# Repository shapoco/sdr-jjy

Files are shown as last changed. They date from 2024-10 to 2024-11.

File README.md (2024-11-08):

# SDR JJY (WIP)

試行錯誤中。

## ハードウェア

恥ずかしながらネットで見つけた構成の切り貼りとカットアンドトライの結果であるため、多分あちこちおかしいと思います。

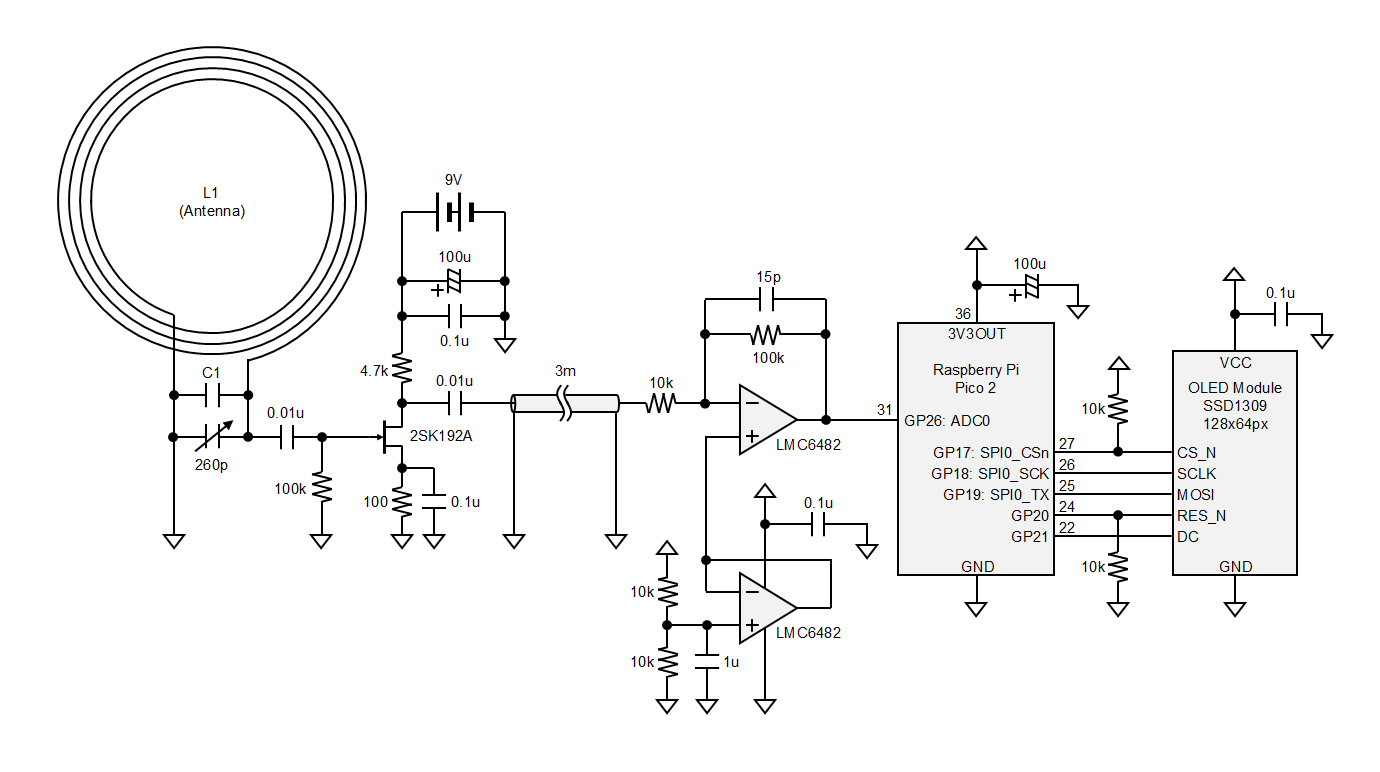
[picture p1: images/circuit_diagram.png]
回路図


市販の電波時計でも窓際でないと受信できないような環境なので、ループアンテナとアンプを窓際に配置し、そこから同軸ケーブルで作業机に引っ張っています。

## ループアンテナ (L1/C1)

西日本 (はがね山送信所) の 60kHz に同調するアンテナです。東日本 (おおたかどや山送信所) の 40kHz に同調させるには、L1 の巻数を増やすか、C1 の容量を増やす必要があります。

### アンテナ仕様

||ループアンテナ<br>200mm版|ループアンテナ<br>400mm版|ペットボトル版|単位|
|:--:|:--:|:--:|:--:|:--:|
|直径|200|400|約65 (※1)|mm|
|巻数|約115|65|約300|turns|
|線径|0.26|0.3|0.18|mm|
|C1容量|1000|1000 + 100|1000 + 470 + 100|pF|

※1) コカ・コーラ社 Qoo 280mL。胴部分は一辺 33mm ほどの六角形

ループアンテナはどちらでも十分安定して受信できました。400mm 版の方が受信強度が強かったのでそちらを使っています。ペットボトル版でも一応受信できましたが、部屋のシーリングライトを消灯しないと信号がノイズに埋もれてしまうなど不安定でした。

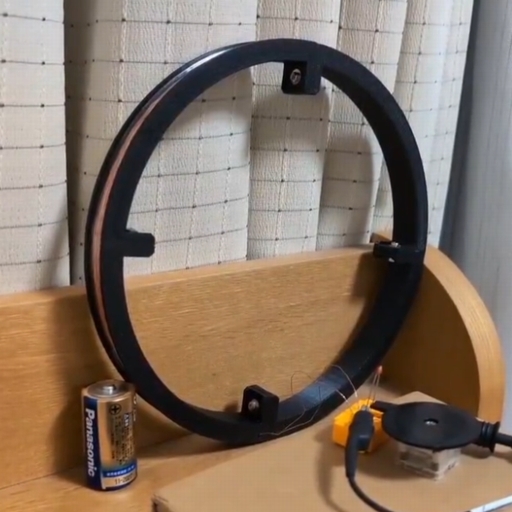
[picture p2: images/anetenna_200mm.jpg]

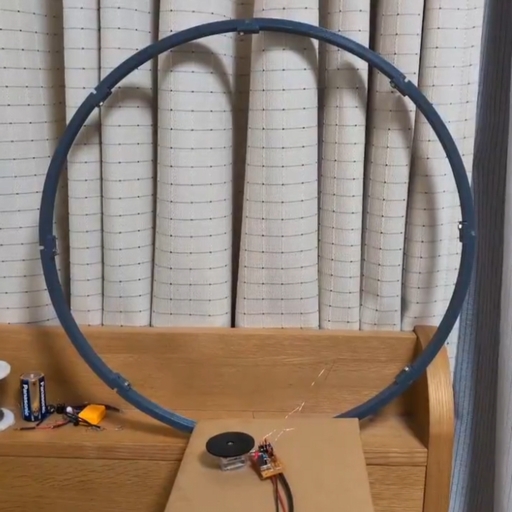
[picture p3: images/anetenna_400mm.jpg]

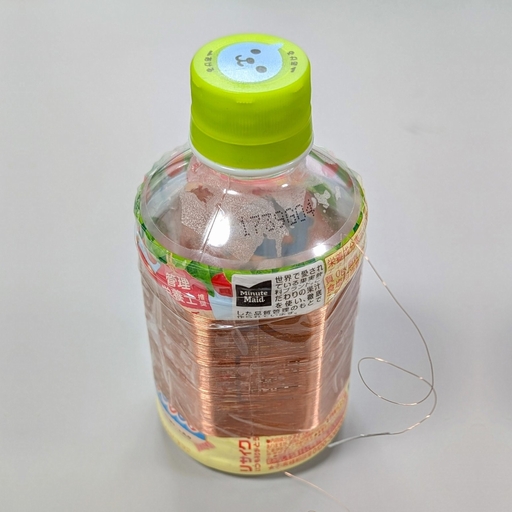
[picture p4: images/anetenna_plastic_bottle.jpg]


### ループアンテナ用 STL

- [loop_antenna_200mm.stl](3dmodel/loop_antenna_200mm.stl)
    - 同じものを 4 個印刷して M3x10 の鍋ネジ x4 で結合
    - 15x15cm のステージで 2 個ずつプリントできます
    - 巻き始め/巻き終わりを引き出す穴や溝がありません
- [loop_antenna_400mm.stl](3dmodel/loop_antenna_400mm.stl)
    - 同じものを 8 個印刷して M3x10 の皿ネジ x8 で結合
    - 15x15cm のステージで 4 個ずつプリントできます

----

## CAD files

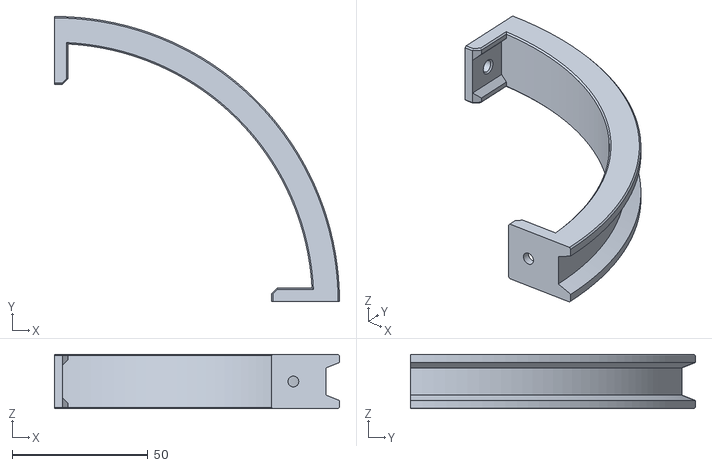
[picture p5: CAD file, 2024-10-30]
3dmodel/loop_antenna_200mm.stl
105.0 x 105.0 x 20.0

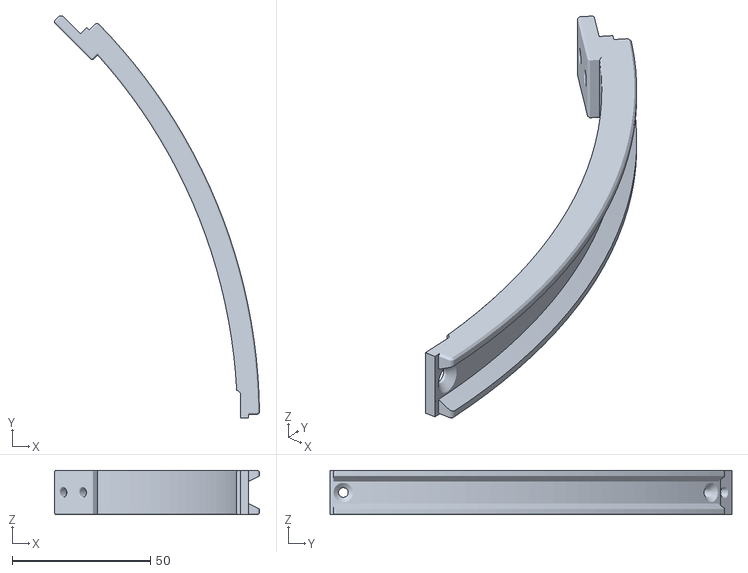
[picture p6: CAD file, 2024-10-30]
3dmodel/loop_antenna_400mm.stl
74.1 x 145.3 x 16.0

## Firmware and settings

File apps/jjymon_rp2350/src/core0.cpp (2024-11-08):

#include <stdio.h>
#include "stdint.h"
#include "math.h"
#include "hardware/clocks.h"
#include "hardware/gpio.h"
#include "hardware/pwm.h"
#include "pico/stdlib.h"
#include "pico/multicore.h"
#include "pico/sync.h"

#include "shapoco/fixed12.hpp"
#include "shapoco/pico/atomic.hpp"
#include "shapoco/pico/dma_adc.hpp"
#include "shapoco/jjy/jjy.hpp"

#include "jjymon.hpp"
#include "core1.hpp"

#define ENABLE_STDOUT (1)

static constexpr uint32_t SYS_CLK_FREQ = 120 * MHZ;
static constexpr uint32_t ADC_SPS = jjy::rx::DETECTION_INPUT_SPS;
static constexpr uint32_t DMA_SIZE = jjy::rx::PREFERRED_DMA_SIZE;

static constexpr int PIN_ADC_IN = 26;
static constexpr int PIN_LED_OUT = 25;
static constexpr int PIN_SPEAKER_OUT = 28;
static constexpr int PIN_LAMP_OUT = 15;

static constexpr uint32_t SPEAKER_FREQ = 440;
static constexpr uint32_t SPEAKER_SAMPLE_BITS = 16;
static constexpr uint32_t SPEAKER_PWM_PERIOD = 1 << SPEAKER_SAMPLE_BITS;

DmaAdc<PIN_ADC_IN, ADC_SPS, DMA_SIZE> dma_adc;
jjy::rx::Receiver receiver;

atomic<receiver_status_t> glb_receiver_status;

static receiver_status_t sts;

int main() {
    set_sys_clock_khz(SYS_CLK_FREQ / KHZ, true);
    sleep_ms(100);

#if ENABLE_STDOUT
    stdio_init_all();
    sleep_ms(500);
    printf("Start.\n");
    printf("receiver.rf.det_delay_ms = %d\n", receiver.rf.det_delay_ms);
    printf("receiver.rf.anti_chat_delay_ms = %d\n", receiver.rf.anti_chat_delay_ms);
#endif

    // Setup fixed-point library
    fxp12::init_tables();

    // Setup LED pin
    gpio_init(PIN_LED_OUT);
    gpio_set_dir(PIN_LED_OUT, GPIO_OUT);

    // Setup Lamp pin
    gpio_init(PIN_LAMP_OUT);
    gpio_set_dir(PIN_LAMP_OUT, GPIO_OUT);

    // Setup speaker out
    {
        gpio_init(PIN_SPEAKER_OUT);
        gpio_set_dir(PIN_SPEAKER_OUT, GPIO_OUT);
        gpio_set_function(PIN_SPEAKER_OUT, GPIO_FUNC_PWM);

        const float pwm_clkdiv = ((float)SYS_CLK_FREQ / SPEAKER_FREQ) / SPEAKER_PWM_PERIOD;
        pwm_config pwm_cfg = pwm_get_default_config();
        pwm_config_set_clkdiv(&pwm_cfg, pwm_clkdiv);
        pwm_config_set_wrap(&pwm_cfg, SPEAKER_PWM_PERIOD - 1);
        pwm_init(pwm_gpio_to_slice_num(PIN_SPEAKER_OUT), &pwm_cfg, true);
        pwm_set_gpio_level(PIN_SPEAKER_OUT, 0);
    }

    adc_init();
    dma_adc.init();
    sleep_ms(100);

    core1_init();
    multicore_launch_core1(core1_main);

    dma_adc.run();

    uint64_t t_last_us = to_us_since_boot(get_absolute_time());
    uint32_t t_dma_us = 0, t_calc_us = 0;
    uint32_t t_next_print_ms = t_last_us / 1000;

    receiver.init(jjy::EAST_40KHZ, to_ms_since_boot(get_absolute_time()));

    while(true) {

        uint64_t t_now_us = to_us_since_boot(get_absolute_time());
        t_calc_us += t_now_us - t_last_us;
        t_last_us = t_now_us;

        const uint16_t* dma_buff = dma_adc.read();

        t_now_us = to_us_since_boot(get_absolute_time());
        t_dma_us += t_now_us - t_last_us;
        t_last_us = t_now_us;
        
        uint32_t t_now_ms = t_now_us / 1000;

        receiver.process(t_now_ms, dma_buff);
        
        sts.rf = receiver.rf.get_status();
        sts.sync = receiver.sync.get_status();
        sts.dec = receiver.dec.get_status();
        glb_receiver_status.store(sts);

        // Output
        gpio_put(PIN_LED_OUT, sts.rf.hyst_dig_out);
        gpio_put(PIN_LAMP_OUT, !sts.rf.digital_out);
        pwm_set_gpio_level(PIN_SPEAKER_OUT, sts.rf.digital_out ? SPEAKER_PWM_PERIOD / 2 : 0);

        if (t_now_ms >= t_next_print_ms) {
            t_next_print_ms += 1000;

#if ENABLE_STDOUT
            float core0usage = (float)(100 * t_calc_us) / (t_calc_us + t_dma_us);
            float gain = (float)sts.rf.agc_gain / (1 << jjy::PREC);
            float qty = (float)sts.rf.signal_quarity / (1 << jjy::PREC);
            int beat_det = sts.rf.beat_detected ? 1 : 0;
            printf("AdcLv:%3d, AGC:%6.2f, Base/Peak:%4d/%4d, Beat=%d, Qty:%4.2f, Core0Usage:%6.2f%%\n",
                (int)sts.rf.adc_amplitude_peak, gain, (int)sts.rf.det_anl_out_base, (int)sts.rf.det_anl_out_peak, beat_det, qty, core0usage);
#endif

            t_calc_us = 0;
            t_dma_us = 0;
        }


    }

    return 0;
}

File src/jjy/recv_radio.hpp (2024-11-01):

#ifndef JJY_RECV_RADIO_HPP
#define JJY_RECV_RADIO_HPP

#include <stdint.h>
#include <math.h>
#include <string.h>

#include "pico/stdlib.h"

#include "jjy/common.hpp"

namespace jjy {


typedef struct {
public:
    uint32_t adc_offset;
    uint32_t agc_amp_raw;
    uint32_t adc_level;
    int32_t adc_min;
    int32_t adc_max;
    uint32_t det_level_raw;
    uint8_t raw_signal;
    uint8_t stabilized_signal;
    uint32_t quarity_raw;

    uint32_t det_threshold;
    uint32_t det_signal_base;
    uint32_t det_signal_peak;

    const float det_level() const { return (float)det_level_raw / (1 << PREC); }
    const float signal_level() const { return (float)(det_level_raw - det_signal_base) / (det_signal_peak - det_signal_base); }
    const float agc_amp() const { return (float)agc_amp_raw / (1 << PREC); }
    const float quarity() const { return (float)quarity_raw / (1 << PREC); }
} rf_status_t;

class Detector {
public:
    static constexpr int32_t ADC_SIGNED_MAX = (1 << (PREC - 1)) - 1;
    static constexpr int32_t ADC_SIGNED_MIN = -(1 << (PREC - 1));

    static constexpr uint32_t AGC_HIST_DEPTH = 20;
    static constexpr uint32_t AGC_HIST_STEP_MS = 1000 / AGC_HIST_DEPTH;

    static constexpr uint32_t AGC_AMP_MIN = 1 << (PREC - 2);
    static constexpr uint32_t AGC_AMP_MAX = 1000 << PREC;

    static constexpr uint32_t DET_HYST_RATIO = (1 << PREC) * 1 / 20;

    static constexpr int ANTI_CHAT_CYCLES = 3; // チャタリング除去の強さ
    static constexpr uint32_t PULSE_WIDTH_LIMIT_MS = 1000; // 最大パルス幅

    static constexpr uint32_t DET_RESO = 1 << 3;
    static constexpr int DET_RESO_60KHZ = DET_RESO;
    static constexpr int DET_RESO_40KHZ = DET_RESO * 3 / 2;
    static constexpr uint32_t DET_PERIOD = lcm(DET_RESO_60KHZ, DET_RESO_40KHZ);

private:
    freq_t freq = freq_t::EAST_40KHZ;

    int32_t sin_table_40kHz[DET_PERIOD];
    int32_t sin_table_60kHz[DET_PERIOD];

    int phase;
    uint32_t accum_adc_level;
    uint32_t accum_det_base;
    uint32_t accum_det_peak;

    int history_index = 0;
    uint32_t history_adc_level[AGC_HIST_DEPTH];
    uint32_t history_det_base[AGC_HIST_DEPTH];
    uint32_t history_det_peak[AGC_HIST_DEPTH];

    uint32_t threshold;
    uint32_t hysteresis;
    uint8_t anti_chat_sreg;
    uint8_t stabilized_signal;

    uint32_t t_one_limit_ms;
    uint32_t t_next_agc_upd_ms;

    rf_status_t status;

public:
    Detector() {
        // sinテーブル
        for (int i = 0; i < DET_PERIOD; i++) {
            sin_table_40kHz[i] = round(sin(i * 2 * M_PI / DET_RESO_40KHZ) * (1 << (PREC - 1)));
        }
        for (int i = 0; i < DET_PERIOD; i++) {
            sin_table_60kHz[i] = round(sin(i * 2 * M_PI / DET_RESO_60KHZ) * (1 << (PREC - 1)));
        }
    }

    void init(freq_t freq) {
        this->freq = freq;

        phase = 0;
        history_index = 0;
        memset(history_adc_level, 0, sizeof(uint32_t) * AGC_HIST_DEPTH);
        memset(history_det_base, 0, sizeof(uint32_t) * AGC_HIST_DEPTH);
        memset(history_det_peak, 0, sizeof(uint32_t) * AGC_HIST_DEPTH);
        accum_adc_level = 0;
        accum_det_base = 0x7fffffff;
        accum_det_peak = 0;
        threshold = 1 << (PREC - 1);
        hysteresis = (threshold * DET_HYST_RATIO) >> PREC;
        anti_chat_sreg = 0;
        stabilized_signal = 0;

        status.adc_offset = (1 << PREC) / 2;
        status.agc_amp_raw = 0;
        status.adc_level = 0;
        status.det_level_raw = 0;
        status.raw_signal = 0;
        status.stabilized_signal = 0;
        status.det_signal_base = 0;
        status.det_signal_peak = 0;
        
        uint64_t t_now_ms = to_ms_since_boot(get_absolute_time());
        t_next_agc_upd_ms = t_now_ms + 1000;
        t_one_limit_ms = t_now_ms;
    }

    uint8_t detect(const uint32_t t_now_ms, const uint16_t *samples, const uint32_t size) {
        uint32_t tmp_adc_accum = 0;
        uint32_t tmp_abs_accum = 0;
        uint32_t tmp_det_accum = 0;
        int32_t tmp_adc_min = (1 << (PREC * 2));
        int32_t tmp_adc_max = -(1 << (PREC * 2));
        for (int i = 0; i < size; i++) {
            uint16_t adc_raw = samples[i];
            tmp_adc_accum += adc_raw;

            // オフセットの減算
            int32_t adc_signed = (int32_t)adc_raw - (int32_t)status.adc_offset;
            tmp_adc_min = JJY_MIN(tmp_adc_min, adc_signed);
            tmp_adc_max = JJY_MAX(tmp_adc_max, adc_signed);

            // AGC
            tmp_abs_accum += JJY_ABS(adc_signed);
            adc_signed = (adc_signed * (int32_t)status.agc_amp_raw) / (1 << PREC);
            adc_signed = JJY_CLIP(ADC_SIGNED_MIN, ADC_SIGNED_MAX, adc_signed);

            // 直交検波
            int32_t sin, cos;
            if (freq == freq_t::EAST_40KHZ) {
                sin = sin_table_40kHz[phase];
                cos = sin_table_40kHz[(phase + DET_RESO_40KHZ / 4) % DET_RESO_40KHZ];
            }
            else {
                sin = sin_table_60kHz[phase];
                cos = sin_table_60kHz[(phase + DET_RESO_60KHZ / 4) % DET_RESO_60KHZ];
            }
            int32_t u = (sin * adc_signed) >> PREC;
            int32_t v = (cos * adc_signed) >> PREC;
            tmp_det_accum += (uint32_t)fast_sqrt(u * u + v * v);
            phase = (phase + 1) % DET_RESO;
        }

        // 振幅
        status.adc_min = tmp_adc_min;
        status.adc_max = tmp_adc_max;

        // オフセットの再計算
        status.adc_offset = tmp_adc_accum / size;

        // ADC 振幅計算
        accum_adc_level = JJY_MAX(accum_adc_level, tmp_abs_accum / size);

        // 直交検波後の信号レベル
        status.det_level_raw = tmp_det_accum / size;
        accum_det_base = JJY_MIN(accum_det_base, status.det_level_raw);
        accum_det_peak = JJY_MAX(accum_det_peak, status.det_level_raw);

        // ヒステリシス
        const uint32_t biased_thresh =
            (anti_chat_sreg & 1) ? threshold - hysteresis : threshold + hysteresis;
        status.raw_signal = (status.det_level_raw >= biased_thresh) ? 1 : 0;

        // チャタリング除去
        anti_chat_sreg = (anti_chat_sreg << 1) & ((1 << ANTI_CHAT_CYCLES) - 1);
        if (status.raw_signal) anti_chat_sreg |= 1;
        if (anti_chat_sreg == 0) {
            stabilized_signal = 0;
        }
        else if (anti_chat_sreg == ((1 << ANTI_CHAT_CYCLES) - 1)) {
            stabilized_signal = 1;
        }

        // パルス幅制限
        if (!stabilized_signal) {
            status.stabilized_signal = 0;
            t_one_limit_ms = t_now_ms + PULSE_WIDTH_LIMIT_MS;
        }
        else if (t_now_ms < t_one_limit_ms) {
            status.stabilized_signal = 1;
        }
        else {
            status.stabilized_signal = 0;
        }

        if (t_now_ms >= t_next_agc_upd_ms) {
            t_next_agc_upd_ms += AGC_HIST_STEP_MS;
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

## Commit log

2024-10-28 add LCD driver
2024-10-30 add antenna stl
    [loop_antenna_200mm.stl, loop_antenna_400mm.stl]
2024-10-30 add circuit diagram
2024-10-30 fix url to STL
2024-11-05 fix circuit diagram
2024-11-13 separate lcd driver base class
2024-11-13 add i2c lcd support
2024-11-13 enable DMA
